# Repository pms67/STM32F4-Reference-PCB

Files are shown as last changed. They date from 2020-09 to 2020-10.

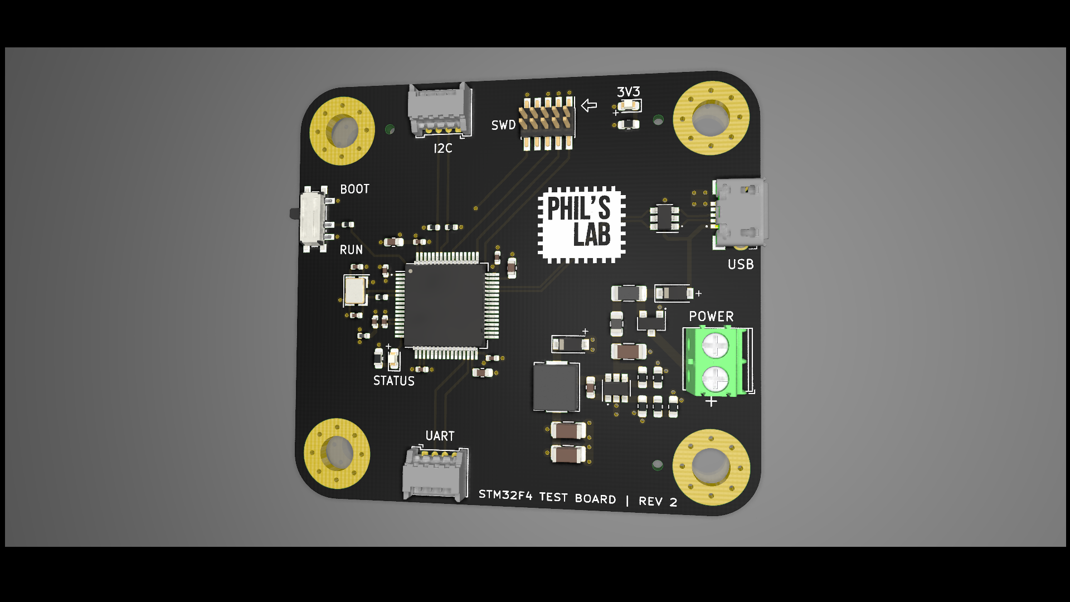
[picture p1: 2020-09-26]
STM32F4_REV2_3D.png

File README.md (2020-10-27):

# STM32F4-Reference-PCB
 KiCad + STM32F4 + USB + Buck converter video reference/test PCB.

- Learn how to design your own STM32-based PCB ([https://youtu.be/x_5rYfAyqq0](https://youtu.be/x_5rYfAyqq0))!
- Learn how to write firmware for the STM32 microcontroller ([https://youtu.be/C7-8nUU6e3E](https://youtu.be/C7-8nUU6e3E))!

You can order this board (incl. SMT assembly) at [https://www.jlcpcb.com](https://www.jlcpcb.com). Gerber and assembly files are in the relevant repo folders.

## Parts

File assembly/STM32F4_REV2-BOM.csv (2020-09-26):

Comment | Designator | Footprint | LCSC
10u | C1,C2,C3 | Capacitor_SMD:C_1206_3216Metric | C13585
1u | C11 | Capacitor_SMD:C_0402_1005Metric | C52923
10n | C12 | Capacitor_SMD:C_0402_1005Metric | C15195
2u2 | C13,C14 | Capacitor_SMD:C_0603_1608Metric | C23630
12p | C15,C16 | Capacitor_SMD:C_0402_1005Metric | C1547
10n | C4 | Capacitor_SMD:C_0603_1608Metric | C57112
4u7 | C5 | Capacitor_SMD:C_0603_1608Metric | C19666
100n | C6,C7,C8,C9,C10 | Capacitor_SMD:C_0402_1005Metric | C1525
B5819W | D1,D2 | Diode_SMD:D_SOD-123 | C8598
RED | D3 | LED_SMD:LED_0603_1608Metric | C2286
BLUE | D4 | LED_SMD:LED_0603_1608Metric | C72041
250mA | F1 | Fuse:Fuse_1206_3216Metric | C369159
600 @ 600MHz | FB1 | Inductor_SMD:L_0805_2012Metric | C1017
MountingHole_Pad | H1,H2,H3,H4 | MountingHole:MountingHole_4.3mm_M4_Pad_Via
Screw_Terminal_01x02 | J1 | TerminalBlock_Phoenix:TerminalBlock_Phoenix_PT-1,5-2-3.5-H_1x02_P3.50mm_Horizontal
SWD | J2 | Connector_PinHeader_1.27mm:PinHeader_2x05_P1.27mm_Vertical_SMD
Conn_01x04 | J3,J4 | Connector_Molex:Molex_PicoBlade_53048-0410_1x04_P1.25mm_Horizontal
USB_B_Micro | J5 | SchmillipKiCADLibrary:USB_MICRO_B_101181930001LF
10u | L1 | Inductor_SMD:L_Sunlord_MWSA0518_5.4x5.2mm | C139506
39n | L2 | Inductor_SMD:L_0402_1005Metric | C26443
AO3401A | Q1 | Package_TO_SOT_SMD:SOT-23 | C15127
100k | R1 | Resistor_SMD:R_0603_1608Metric | C25803
2k2 | R10,R11 | Resistor_SMD:R_0402_1005Metric | C25879
68k | R2 | Resistor_SMD:R_0603_1608Metric | C23231
47k | R3 | Resistor_SMD:R_0603_1608Metric | C25819
15k | R4 | Resistor_SMD:R_0603_1608Metric | C22809
270 | R5 | Resistor_SMD:R_0603_1608Metric | C22966
1k | R6 | Resistor_SMD:R_0603_1608Metric | C21190
10k | R7 | Resistor_SMD:R_0402_1005Metric | C25744
47 | R8 | Resistor_SMD:R_0402_1005Metric | C25118
1k5 | R9 | Resistor_SMD:R_0603_1608Metric | C22843
SW_SPDT | SW1 | Button_Switch_SMD:SW_SPDT_PCM12
MP2359DJ-LF-Z | U1 | Package_TO_SOT_SMD:SOT-23-6 | C14259
STM32F405RGT6 | U2 | Package_QFP:LQFP-64_10x10mm_P0.5mm | C15742
USBLC6-2SC6 | U3 | Package_TO_SOT_SMD:SOT-23-6 | C7519
16MHz | Y1 | Crystal:Crystal_SMD_3225-4Pin_3.2x2.5mm | C13738

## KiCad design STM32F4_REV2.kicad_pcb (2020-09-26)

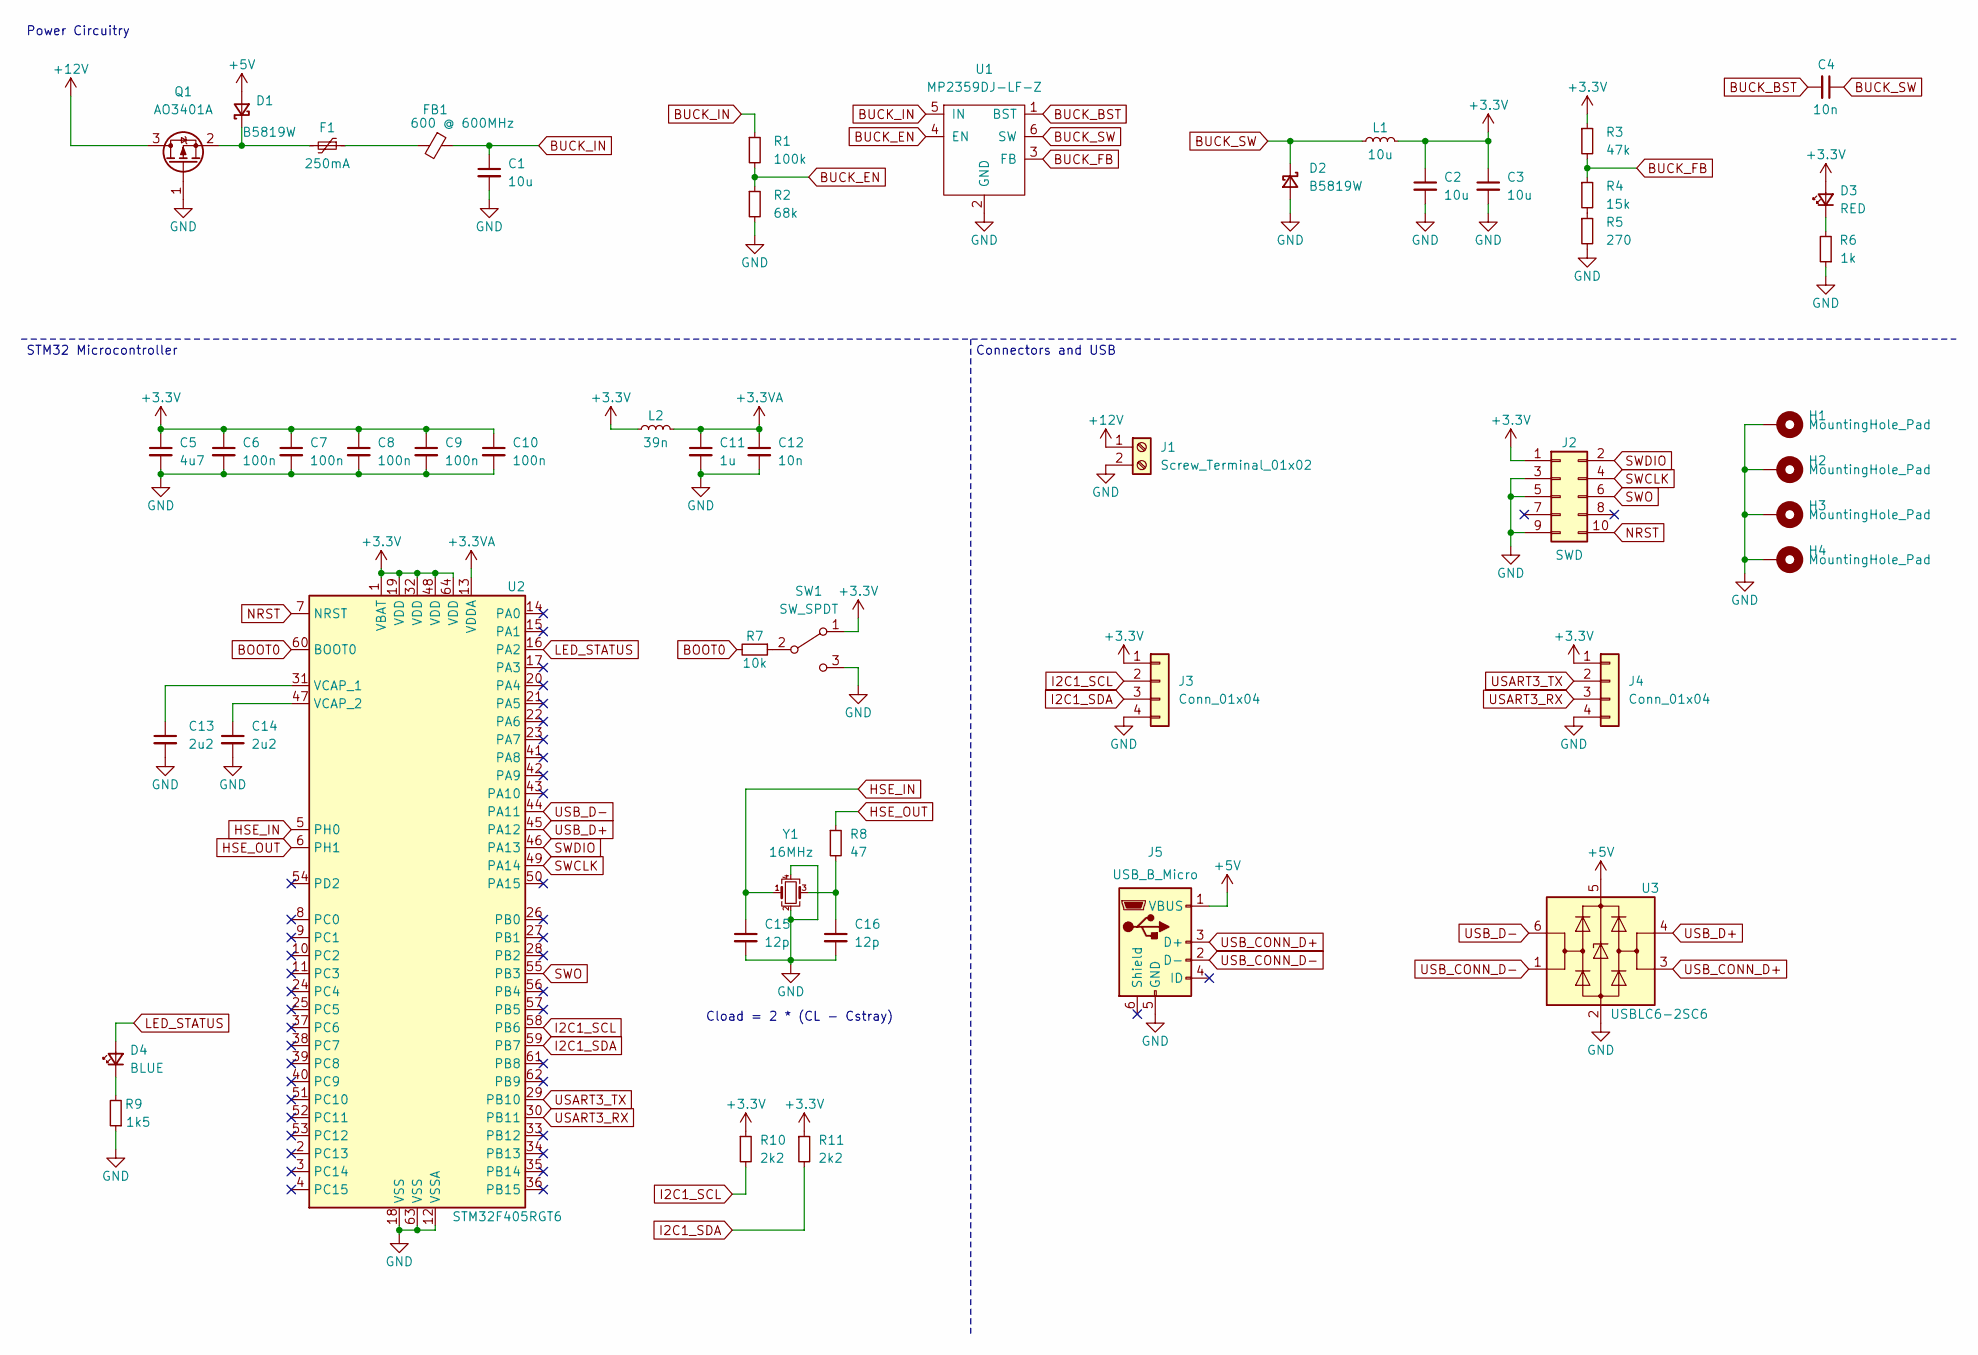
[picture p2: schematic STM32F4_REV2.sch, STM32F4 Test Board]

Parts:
C1, C2, C3: 10u; C_1206_3216Metric; LCSC Part # C13585
C4: 10n; C_0603_1608Metric; LCSC Part # C57112
C5: 4u7; C_0603_1608Metric; LCSC Part # C19666
C6, C7, C8, C9, C10: 100n; C_0402_1005Metric; LCSC Part # C1525
C11: 1u; C_0402_1005Metric; LCSC Part # C52923
C12: 10n; C_0402_1005Metric; LCSC Part # C15195
C13, C14: 2u2; C_0603_1608Metric; LCSC Part # C23630
C15, C16: 12p; C_0402_1005Metric; LCSC Part # C1547
D1, D2: B5819W; D_SOD-123; LCSC Part # C8598
D3: RED; LED_0603_1608Metric; LCSC Part # C2286
D4: BLUE; LED_0603_1608Metric; LCSC Part # C72041
F1: 250mA; Fuse_1206_3216Metric; LCSC Part # C369159
FB1: 600 @ 600MHz; L_0805_2012Metric; LCSC Part # C1017
H1, H2, H3, H4: MountingHole_Pad; MountingHole_4.3mm_M4_Pad_Via
J1: Screw_Terminal_01x02; TerminalBlock_Phoenix_PT-1,5-2-3.5-H_1x02_P3.50mm_Horizontal
J2: SWD; PinHeader_2x05_P1.27mm_Vertical_SMD
J3, J4: Conn_01x04; Molex_PicoBlade_53048-0410_1x04_P1.25mm_Horizontal
J5: USB_B_Micro; USB_MICRO_B_101181930001LF
L1: 10u; L_Sunlord_MWSA0518_5.4x5.2mm; LCSC Part # C139506
L2: 39n; L_0402_1005Metric; LCSC Part # C26443
Q1: AO3401A; SOT-23; LCSC Part # C15127
R1: 100k; R_0603_1608Metric; LCSC Part # C25803
R2: 68k; R_0603_1608Metric; LCSC Part # C23231
R3: 47k; R_0603_1608Metric; LCSC Part # C25819
R4: 15k; R_0603_1608Metric; LCSC Part # C22809
R5: 270; R_0603_1608Metric; LCSC Part # C22966
R6: 1k; R_0603_1608Metric; LCSC Part # C21190
R7: 10k; R_0402_1005Metric; LCSC Part # C25744
R8: 47; R_0402_1005Metric; LCSC Part # C25118
R9: 1k5; R_0603_1608Metric; LCSC Part # C22843
R10, R11: 2k2; R_0402_1005Metric; LCSC Part # C25879
SW1: SW_SPDT; SW_SPDT_PCM12
U1: MP2359DJ-LF-Z; SOT-23-6; LCSC Part # C14259
U2: STM32F405RGT6; LQFP-64_10x10mm_P0.5mm; LCSC Part # C15742
U3: USBLC6-2SC6; SOT-23-6; LCSC Part # C7519
Y1: 16MHz; Crystal_SMD_3225-4Pin_3.2x2.5mm; LCSC Part # C13738

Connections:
+3.3VA: C11.1, C12.1, L2.2, U2.13 (VDDA)
+3V3: C2.1, C3.1, C5.1, C6.1, C7.1, C8.1, C9.1, C10.1, D3.2 (A), J2.1, J3.1, J4.1, L1.2, L2.1, R3.1, R10.1, R11.1, SW1.1 (A), U2.1 (VBAT), U2.19 (VDD), U2.32 (VDD), U2.48 (VDD), U2.64 (VDD)
+5V: D1.2 (A), J5.1 (VBUS), U3.5 (VBUS)
+12V: J1.1, Q1.3 (D)
BOOT0: R7.2, U2.60 (BOOT0)
BUCK_BST: C4.2, U1.1 (BST)
BUCK_EN: R1.2, R2.1, U1.4 (EN)
BUCK_FB: R3.2, R4.1, U1.3 (FB)
BUCK_IN: C1.1, FB1.1, R1.1, U1.5 (IN)
BUCK_SW: C4.1, D2.1 (K), L1.1, U1.6 (SW)
GND: C1.2, C2.2, C3.2, C5.2, C6.2, C7.2, C8.2, C9.2, C10.2, C11.2, C12.2, C13.2, C14.2, C15.2, C16.2, D2.2 (A), H1.1, H2.1, H3.1, H4.1, J1.2, J2.3, J2.5, J2.9, J3.4, J4.4, J5.5 (GND), Q1.1 (G), R2.2, R5.2, R6.1, R9.1, SW1.3 (C), U1.2 (GND), U2.12 (VSSA), U2.18 (VSS), U2.63 (VSS), U3.2 (GND), Y1.2, Y1.4
HSE_IN: C15.1, U2.5 (PH0), Y1.1
HSE_OUT: R8.1, U2.6 (PH1)
I2C1_SCL: J3.2, R10.2, U2.58 (PB6)
I2C1_SDA: J3.3, R11.2, U2.59 (PB7)
LED_STATUS: D4.2 (A), U2.16 (PA2)
NRST: J2.10, U2.7 (NRST)
unnamed: C13.1, U2.31 (VCAP_1)
unnamed: C14.1, U2.47 (VCAP_2)
unnamed: C16.1, R8.2, Y1.3
unnamed: D1.1 (K), F1.2, Q1.2 (S)
unnamed: D3.1 (K), R6.2
unnamed: D4.1 (K), R9.2
unnamed: F1.1, FB1.2
unnamed: R4.2, R5.1
unnamed: R7.1, SW1.2 (B)
SWCLK: J2.4, U2.49 (PA14)
SWDIO: J2.2, U2.46 (PA13)
SWO: J2.6, U2.55 (PB3)
USART3_RX: J4.3, U2.30 (PB11)
USART3_TX: J4.2, U2.29 (PB10)
USB_CONN_D+: J5.3 (D+), U3.3 (I/O2)
USB_CONN_D-: J5.2 (D-), U3.1 (I/O1)
USB_D+: U2.45 (PA12), U3.4 (I/O2)
USB_D-: U2.44 (PA11), U3.6 (I/O1)

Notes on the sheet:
Cload = 2 * (CL - Cstray)
STM32 Microcontroller
Power Circuitry
Connectors and USB

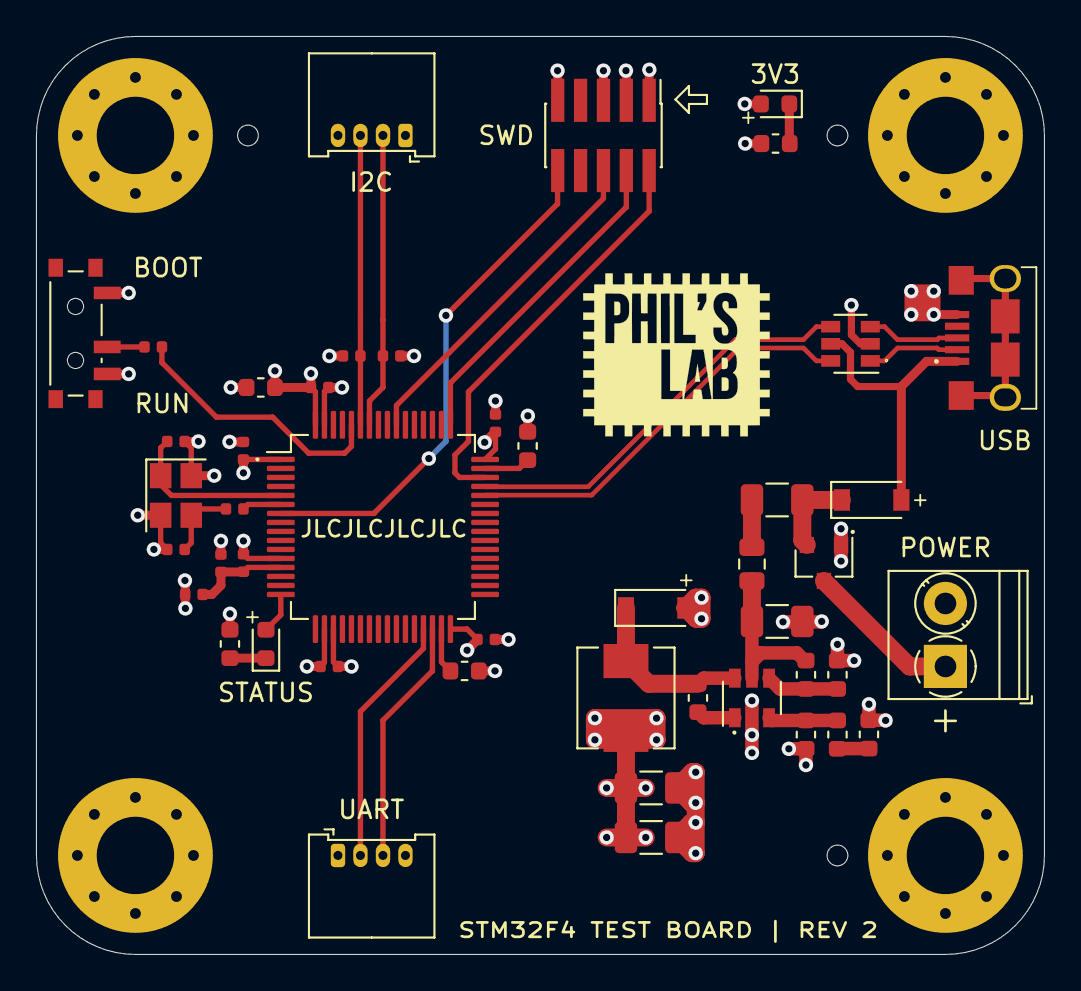
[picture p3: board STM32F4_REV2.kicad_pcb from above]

Board: 4 copper layers, 56.0 x 51.0 mm, 50 parts (0 on the bottom side), 35 nets.

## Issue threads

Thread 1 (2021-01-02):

Question about the P-MOSFET in the input of 12v power

cheng3100, 2021-01-02:
Hi, I look the entire video on youtube and I'm very interesting to make one. But I have a question about the P-MOSFET in the input of 12v power, What is its function? It is not work as a switch nor a amplifier.   I see you explain that its function is "Reverse Voltage Protection ". But why? It should be conduct in both direction if the voltage of g is low(on). It really confuse me. Can you give me more details about this？

Calmhands, 2021-01-03:
@cheng3100  Take a look at this video. This guy will explain it better than I can. https://www.youtube.com/watch?v=IrB-FPcv1Dc&ab_channel=Afrotechmods

cheng3100, 2021-01-05:
But I still have a questions, about the direction of current. Almost all the book say that the current should flow from S to D for P-MOSFET and from D to S for N-MOSFET. But in the reverse protection circuite it is from D to S for the P-MOSFET. So can I say both direction for MOSFET is ok?

cheng3100, 2021-01-05:
Or can I just exchange the d and s in the reverse protection circuit？

Closed 2021-02-21.

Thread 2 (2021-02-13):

Question about remove the reference and value sink from pcb?

cheng3100, 2021-02-13:
Hi, I check your pcb file and found that your board is "clean" and without the annoying reference and value sink. Is there anyway to remove them? I search for a while and found nothing....My board is like this:
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

cheng3100, 2021-02-14:
Hi, I found the method to batch change the layer of reference from silk to fab. Just in the `Edit` -> `Edit Text and Graphic Properties`. Now everything is fine.

Closed 2021-02-21.
